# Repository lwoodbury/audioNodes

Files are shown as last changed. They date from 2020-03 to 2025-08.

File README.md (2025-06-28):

# audioNodes
Raspberry Pi based Smart Speaker Network designed to run Pure Data patches for sonic arts. 

- small and fairly powerful with good audio quality (I2S 3W amplifier)
- contains a Lipo battery and manages charging via USB micro
- has a smart power switch (safe shutdown and power off)
- everything shared here under Creative Commons Attribution-ShareAlike 4.0 International License, the Raspberry Pi image *, laser cut designs, code and circuit designs. The safe shutdown circuitry and code are inspired by the NeonHorizon/lipopi repo which is covered by a GPL 3.0 licence. Go forth and prosper...

<br />This work is licensed under a <a rel="license" href="http://creativecommons.org/licenses/by-sa/4.0/">Creative Commons Attribution-ShareAlike 4.0 International License</a>.

The idea is to run audio nodes that can communicate with each other using OSC in PD and eventually add sensors and microphone input (and possibly some extra output functionality). The hardware is a development from my digital 'birds' installation: https://www.dotlib.org/home#/forest-of-imagination-2018/

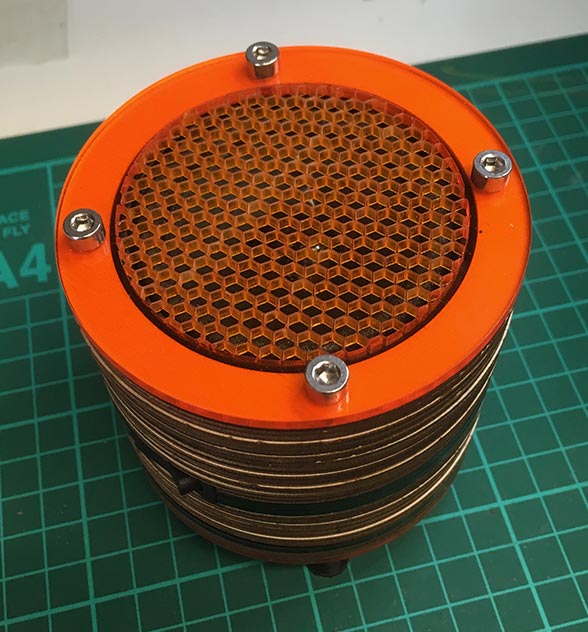
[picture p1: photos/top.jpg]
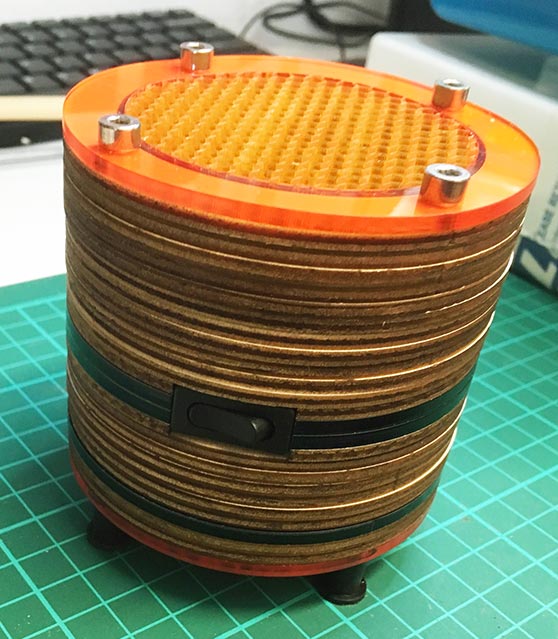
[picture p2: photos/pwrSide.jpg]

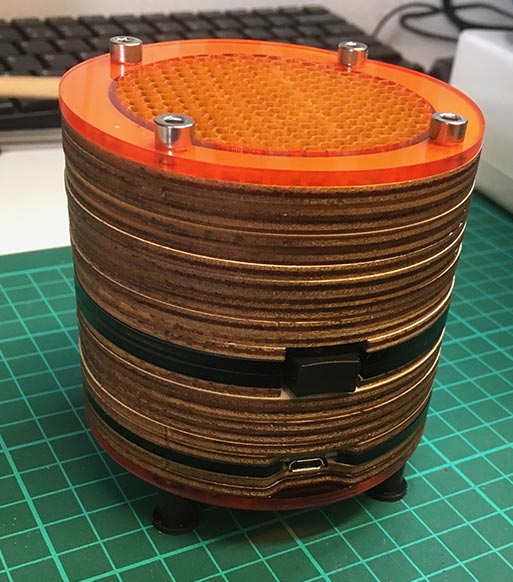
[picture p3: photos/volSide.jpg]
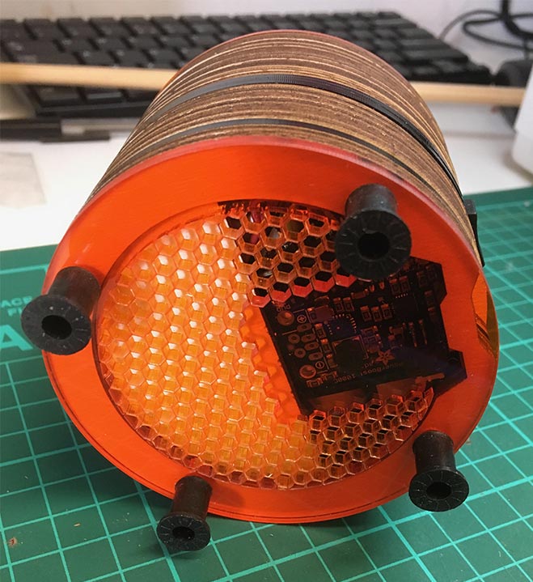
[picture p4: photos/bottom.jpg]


This project is at an early stage and the documentation is not yet as clear as it could be, I have just taken on a new full time job and am not sure when I can next update it or add details on the OSC communication part. Happpy to accept any help in this respect!

To build your own, check out the BOM (bill of materials) spreadsheet for required components and follow the 'Building an Audio Node' document with reference to the 'build stage photos' and notes. The lasercut designs make use of a deep engrave to go around some of the components, you will have to work this out based on your material and laser cutter model.

* Raspberry Pi image can be download from here: https://www.dropbox.com/s/5uapjz6rh7yxo8m/raspbianImage.img.zip?dl=1

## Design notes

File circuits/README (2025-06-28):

The power management circuit and code was inspired by NeonHorizon's 'lipopi' repo:
https://github.com/NeonHorizon/lipopi

Included here is a stripboard version and a PCB version, currently the case designs are based on the stripboard version. 

Use the file here to make new PCBs; unfortunately the original version of the KiCad project was lost but you can make new gerbers from this one:
..\circuits\powerManager\PCB files\Recovered_LiPoPiShutdown\LiPoPiShutdown.kicad_pcb

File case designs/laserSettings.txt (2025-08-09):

Trotec Speedy 360

Cut: P 100 V 1.5
Deep engrave 1mm: P 50 V 34

Lose 5mm from each side of strip on layer 11
Layer 23 engrave needs to be deeper 
Layer 24 can be lost?

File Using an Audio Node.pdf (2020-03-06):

## Using an Audio Node

## Turning it off and on

The frosted/clear section allows you to see the Raspberry Pi’s green light, when it is flashing it means disk activity. On the base you can also see the Power Boost board lights.

The power button must be held on for a short time for the power to stay up. Through the frosted section of the case you can see the Raspberry Pi’s green light flashing to indicate activity as it starts up. When the light is solid the Pi is ready, you should hear the speaker pop and then if you have set your PD patch to open on boot it should start a moment later.

To turn off you can do a short click of the button, the device should kill PD, start a safe shutdown and then once that is complete cut the power on the Power Boost board at which time the blue light will go off. This takes a little time, a minute or two.

## Controlling the device via a terminal with SSH

Make sure your computer/device is on the same network as the pi and open a terminal. SSH into the pi with: ssh pi@raspberrypi.local password: raspberry , or whatever hostname and password you have set up already
(kudos to ‘Termius’ which enables you to store snippets of terminal commands and communicate with the device from your phone easily)

Some useful SSH commands:
Software Mixer – alsamixer
Speaker test (noise) - speaker-test -c2

Speaker test (WAV) - speaker-test -c2 --test=wav -w /usr/share/sounds/alsa/Front_Center.wav

Install MP3 stream player - sudo apt-get install -y mpg123

Play Radio 6 stream - mpg123 http://bbcmedia.ic.llnwd.net/stream/bbcmedia_6music_mf_p

Edit boot config file - sudo nano /boot/config.txt
Crontab edit - crontab -e
Configure Raspberry Pi - sudo raspi-config

Set time - sudo date -s "9/26/2018 9:35"

Shutdown - sudo shutdown -h now

Update - sudo apt-get update && sudo apt-get upgrade

Wifi scan - sudo iwlist wlan0 scan

## Accessing a Remote Desktop

I have left VNC enabled and am running in GUI mode (i.e. not headless) so you should be able to connect with a VNC client of which there are several free ones, I use ‘VNC Viewer’.

You need to put in your hostname and password details and again assure you are on the same network as the Pi. If you can not connect, then SSH in as above and:

1. Run configuration tool with: sudo raspi-config
2. Check that VNC is enabled (in ‘Interfacing Options’)
3. Check that boot options are not set to go into console, i.e. run headless

## Transferring Files

Transferring files can be done via FTP, again there are several free options, I use ‘Filezilla’. You need to put in your hostname and password details and assure you are on the same network as the Pi. You can then simply drag and drop files from your system to the device.

## Working with PD

I have not had much success trying to get anything other than PD vanilla running on the Pi Zero, but in fairness I have not tried for a while and it could be possible to run one of the more feature rich forks such as Purr Data or perhaps the L2Ork distribution.

## Getting your PD patch to run on startup

Refer to the ‘Building and Audio Node’ document, specifically the section titled ‘To create your own image’, steps 17 & 18 (or you could just rename your patch and move it to the same place as the original one)

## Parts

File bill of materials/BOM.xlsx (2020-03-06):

Item | Cost | Dimensions (mm) | Link
Speaker (66mm) | £5.50 | 66x66x29 | https://shop.pimoroni.com/products/5w-4-ohm-65mm-full-range-speaker
DAC & amplifier: Adafruit Speaker Bonnet | £12.00 | 65x30x7.2 | https://shop.pimoroni.com/products/adafruit-i2s-3w-stereo-speaker-bonnet-for-raspberry-pi-mini-kit
Lipo battery (2000mAh) | £13.50 | 64x35.5x5.3 | https://shop.pimoroni.com/products/lipo-battery-pack?variant=20429082247
Lipo boost/charger: Adafruit PowerBoost 1000c | £18.30 | 10 | https://shop.pimoroni.com/products/powerboost-1000-charger-rechargeable-5v-lipo-usb-boost-1a-1000c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
Raspberry Pi Zero WH | £13.02 | 65x30x5 | https://shop.pimoroni.com/products/raspberry-pi-zero-wh-with-pre-soldered-header
Micro SD Card | £6.65 |  | https://www.mymemory.co.uk/samsung-32gb-evo-micro-sd-card-sdhc-uhs-i-u1-adapter-95mb-s.html
Acrylic sheet (3x400x600mm) [main body] | £7.50 |  | https://www.kitronik.co.uk/4365-black-opaque-perspex-sheet-3mm-x-600mm-x-400mm.html
Acrylic sheet (3x200x100mm) [base & top] | £0.80 |  | https://www.kitronik.co.uk/43115-grey-perspex-sheet-frosted-3mm-x-600mm-x-400mm.html
Acrylic sheet (3x100x100mm) [illuminating section] | £0.40 |  | https://www.kitronik.co.uk/4391-white-frosted-perspex-sheet-3mm-x-600mm-x-400mm.html
On/Off button (momentary rocker) | £2.45 |  | https://sinolec.co.uk/en/miniature-rocker-switches/1211391-slim-rocker-switch-momentary-on.html
Volume rocker button: RS stock 734-6883 | £1.77 |  | https://uk.rs-online.com/web/p/rocker-switches/7346883/?searchHistory=%7B%22enabled%22%3Atrue%7D
4x M4 80mm screws | £1.25 |  | https://www.kayfast.co.uk/view-product/SOCKET-CAP-SCREWS-DIN-912-A2-ST-ST
4x M4x11mm rubber nuts | £1.50 |  | https://www.kayfast.co.uk/view-product/RUBBER-WELL-NUTS
Sundries:
Stripboard (10x10 holes) | £0.35
Resistors (2x 100K, 1x 10K, 1x 33K) | £0.08
Diode (1x 1N4001) | £0.05
Capacitor (1x 100uF) | £0.26
Right angle header pins (9x) | £0.80
Header sockets (1x 5, 2x 2) | £0.80
Wires, solder etc
Postage and sundries | £6.00
TOTAL | £92.98
Laser Cutting time:
Main sides | 35 mins
2x ends | 12 mins
1x frosted section | 3 mins
Cleaning up of parts | 10 mins
Micro SD preparation and software config time | 15 mins
Soldering power board and parts prep time | 30 mins
Assembly time + connecting wires soldering | 30 mins
Ordering time | 30 mins

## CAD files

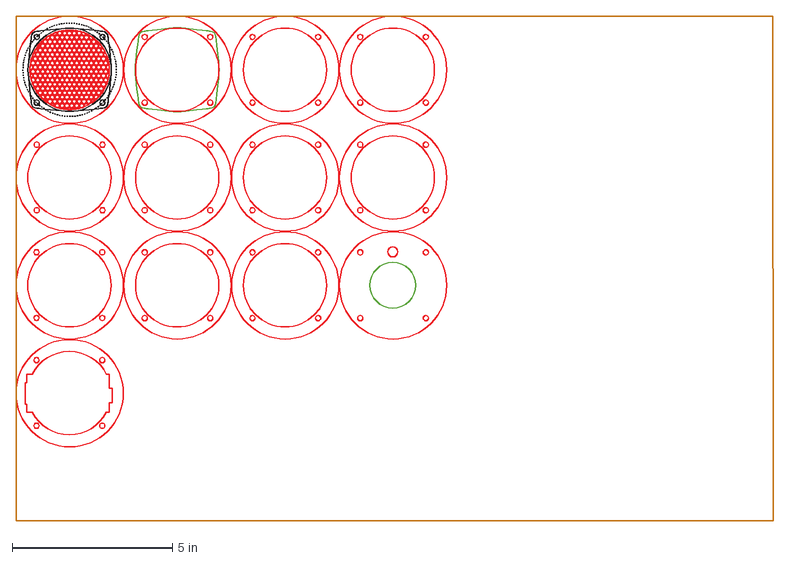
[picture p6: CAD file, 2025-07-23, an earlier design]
case designs/archive/case.dxf
23.6 x 15.8 in

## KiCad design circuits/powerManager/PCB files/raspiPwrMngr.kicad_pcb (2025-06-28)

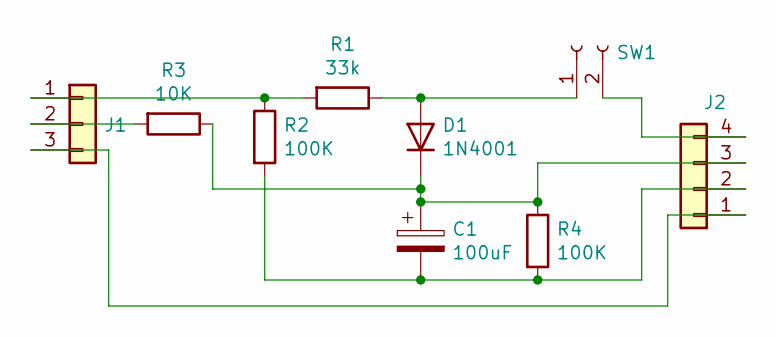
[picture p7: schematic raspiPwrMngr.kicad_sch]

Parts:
C1: 100uF; CP_Radial_D8.0mm_P5.00mm
D1: 1N4001; D_DO-41_SOD81_P10.16mm_Horizontal
J1: Conn_01x03; JST_PH_S3B-PH-K_1x03_P2.00mm_Horizontal
J2: Conn_01x04; JST_PH_S4B-PH-K_1x04_P2.00mm_Horizontal
R1: 33k; R_Axial_DIN0207_L6.3mm_D2.5mm_P10.16mm_Horizontal
R2, R4: 100K; R_Axial_DIN0207_L6.3mm_D2.5mm_P10.16mm_Horizontal
R3: 10K; R_Axial_DIN0207_L6.3mm_D2.5mm_P10.16mm_Horizontal
SW1: Conn_01x02_Socket; JST_PH_S2B-PH-K_1x02_P2.00mm_Horizontal

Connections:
unnamed: D1.2 (A), R1.1, SW1.1
unnamed: C1.1, D1.1 (K), J2.3, R3.1, R4.1
unnamed: J1.1, R1.2, R2.1
unnamed: J1.2, R3.2
unnamed: J1.3, J2.1
unnamed: C1.2, J2.2, R2.2, R4.2
unnamed: J2.4, SW1.2

Board: 2 copper layers, 9 parts (0 on the bottom side), 7 nets, no tracks yet.

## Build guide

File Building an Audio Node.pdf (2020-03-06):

## Building an Audio Node

## Part 1 – Getting the SD card image sorted

You can either download the pre-built image or build the image yourself, if using the prebuilt you will still need to set up your Wifi networks as shown below.

Using the prebuilt image
Download the pre-built image from here, this includes Raspbian, PD, volume control button service, shutdown service that works together with the external circuit and Power Boost board. You will need to set up the wifi credentials to connect to the device:
1. Use ‘Pi Filler’ app or similar to load the image onto the SD card
2. Mount the SD card from a computer
3. Create a text file in the root folder and rename it: wpa_supplicant.conf
4. Use a text editor to edit the wifi settings file you have just created with the entry below, you can add several networks. For example you can set up your home, work, a little portable router and an access point on your phone to cover all bases. You can also add a connection priority (e.g. ‘priority=1’) to each entry:

ctrl_interface=DIR=/var/run/wpa_supplicant GROUP=netdev update_config=1
country=UK

network={
ssid="YOURSSID"
psk="YOURPASSWORD"
scan_ssid=1
}
5. Eject the SD card and run through steps 6 – 11 in the section below

## To create your own image:

1. Download Raspbian image and unzip: https://www.raspberrypi.org/downloads/raspbian/
a. [You will need the desktop version if you plan to VNC across to remote control the desktop using the GUI. This can be useful to set up PD and then you can disable the GUI, i.e run ‘headless’, later]
2. Use PiFiller or similar to load up SD card with the image
3. Add a text file for wifi settings to root folder called: wpa_supplicant.conf

4. Edit the wifi settings file with following, you can add several networks. For example you can set up your home, work, a little portable router and an access point on your phone to cover all bases. You can also add a connection priority (e.g. ‘priority=1’) to each entry:
a. ctrl_interface=DIR=/var/run/wpa_supplicant GROUP=netdev
b. update_config=1
c. country=UK
d. network={
e. ssid="YOURSSID"
f. psk="YOURPASSWORD"
g. scan_ssid=1
h. }
5. Add a blank text file to root folder simply called ‘ssh’ with no file type
6. Insert SD card and boot up Pi
7. Make sure your computer/device is on the same network as the pi and open a terminal. SSH into the pi with: ssh pi@raspberrypi.local password: raspberry , or whatever hostname and password you have set up already
(kudos to ‘Termius’ which enables you to store snippets of terminal commands and communicate with the device from your phone easily)
8. Run configuration tool with: sudo raspi-config
9. Change hostname (in ‘Network Options’), change password, enable VNC (in ‘Interfacing Options’), you may also want to set the locale and time zone while you are here
10. If you are going to want to schedule things you will need to set the time which you can do manually (sudo date -s "2/26/2020 9:35"), but it will be forgotten when the battery is disconnected. Alternatively you could try installing NTP so it updates automatically when you have a network connection: sudo apt-get install ntp
11. Reboot Pi
12. Do the updates (it may take a while). Run:

sudo apt-get update && sudo apt-get upgrade

13. Install PD: sudo apt-get install puredata
14. Set up Adafruit Speaker Bonnet: https://learn.adafruit.com/adafruit-speakerbonnet-for-raspberry-pi/raspberry-pi-usage
15. Open PD, setup audio and SAVE audio settings! I needed to use portaudio driver to make it work, also need to set the output device to ‘softvol’ to be able to control the volume from the alsamixer and via the button code.
16. Copy main PD patch across – Use an FTP client

17. Set up a script to open PD patch and run without the GUI if desired:
a. Create the script: sudo nano /home/pi/pdstart
b. Add following lines (watch filepath and case!!) :

sleep 5
pd -nogui -nomidi -verbose -stderr /home/pi/Documents/Pd/PDSamplePlay/playSample.pd sleep 5
c. Set privileges on script with:

sudo chmod 755 /home/pi/pdstart

d. Start script with : /home/pi/pdstart
(Can kill PD with: sudo killall pd )
18. You can add script to startup and schedule with crontab if desired: https://www.raspberrypi.org/documentation/linux/usage/cron.md
**NB- using cron reboot function may mean the script starts before home drive is mounted or audio is enabled etc, the lazy can simply add an arbitrary delay to the script and hope it sorts it, or systemd could be used to do it properly and start it later in boot process details for using systemd here: https://www.dexterindustries.com/howto/run-a-program-on-your-raspberry-pi-atstartup/
19. If you wish to cut the GUI side of the Pi and save system resources then go into raspi-config and select boot options to go into console, i.e. run headless
20. Disable Bluetooth if desired to save battery:
21. Edit boot config file: sudo nano /boot/config.txt
… and add these lines to bottom:

# Disable Bluetooth

dtoverlay=pi3-disable-bt

## Part 2 – Getting the Volume and Power Button sorted

## Volume control – connected buttons to GPIO pins 4 and 17

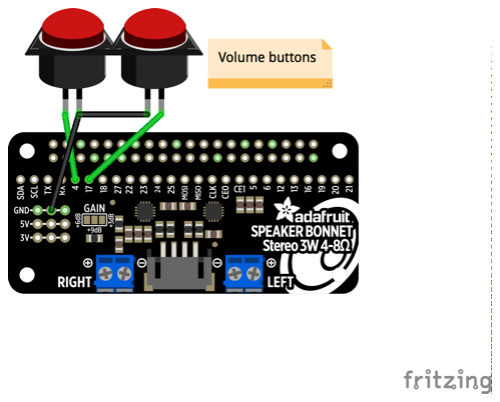
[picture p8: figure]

NB - The below works for system sound control via alsamixer, this means you may need to set the output device in PD to ‘softvol’ to get it to work

1. To create python script - sudo nano volButton.py
2. Insert the Python script code below:

import RPi.GPIO as GPIO
import time

GPIO.setmode(GPIO.BCM)

GPIO.setup(4, GPIO.IN, pull_up_down=GPIO.PUD_UP) GPIO.setup(17, GPIO.IN, pull_up_down=GPIO.PUD_UP)

while True:
volUp = GPIO.input(4)
if volUp == False:
print('UP Button Pressed')
#amixer set PCM 3%+

from subprocess import call call(["amixer", "set", "PCM", "3%+"]) #amixer set Speaker 5%+
time.sleep(0.2)

volDwn = GPIO.input(17)
if volDwn == False:
print('DOWN Button Pressed')
#amixer set PCM 3%-

from subprocess import call call(["amixer", "set", "PCM", "3%-"]) #amixer set Speaker 5%-
time.sleep(0.2)
3. Set the script up to run as a service, follow ‘Method 4: SYSTEMD’ at this link or the one below with the service code below.
- https://www.dexterindustries.com/howto/run-a-program-on-your-raspberry-pi-atstartup/#local
- https://github.com/bruceiow/rPiVolumeControl/blob/master/setup.md

[Unit]
Description=Volume Controller
After=multi-user.target

[Service]
Type=idle
ExecStart=/usr/bin/python /home/pi/volButton.py > /home/pi/volButton.log 2>&1

[Install]
WantedBy=multi-user.target

## On/off button – using ‘lipopi’ resource

NB – Note use of pin 27 instead of pin 18 as used in the ‘lipopi’ resource. This is because the speaker bonnet makes use of pin 18

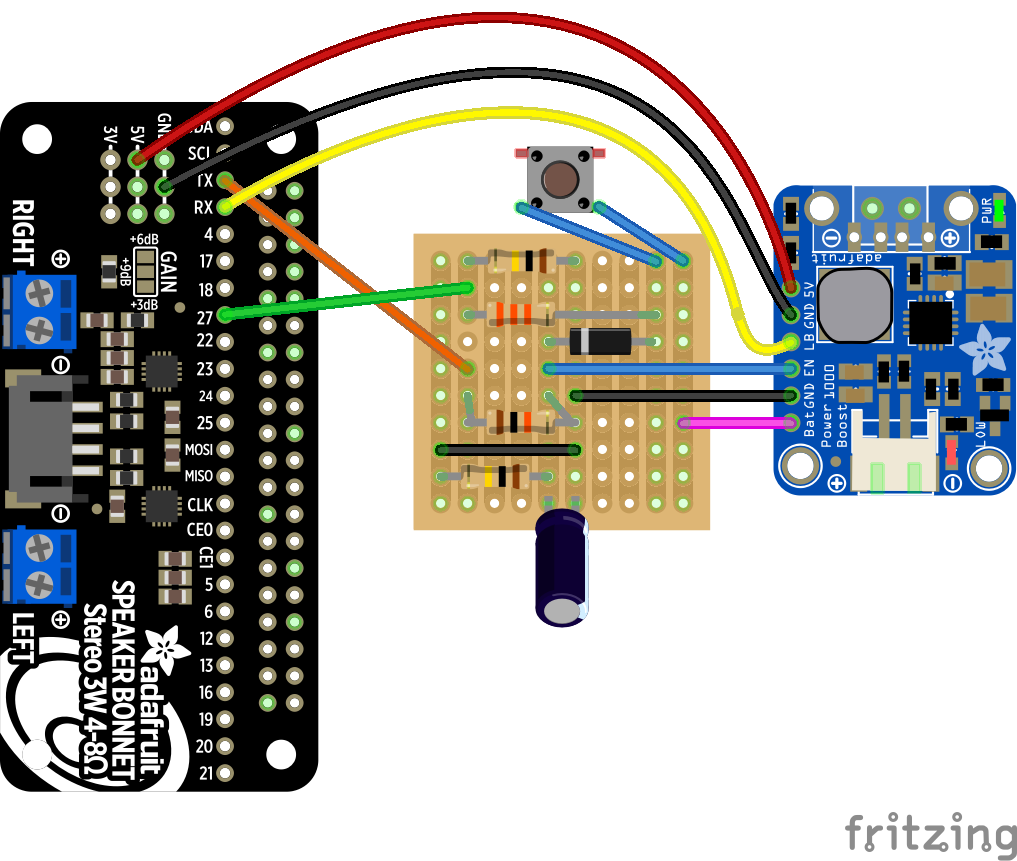
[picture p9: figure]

LiPoPi
https://github.com/NeonHorizon/lipopi/blob/master/README.power_up_power_down.md

[NB I found that the service was failing when I tried to run it and had to chmod on the original script to make it executable (probably because I added the script myself instead of copying the repository one over): sudo chmod +x lipopi.py]

I wanted the shutdown button press to also kill PD so I added to the lipopi.py script where shutdown or low battery is triggered: os.system("sudo killall pd")
e.g:

# Detect when the switch is pressed - wait shutdown_wait seconds - then shutdown

def lipopi_user_shutdown(channel):
global lipopi

cmd = "sudo wall 'System shutting down in %d seconds'" % lipopi['shutdown_wait'] os.system(cmd)
os.system("sudo killall pd")
time.sleep(lipopi['shutdown_wait'])

msg = time.strftime("User Request - Shutting down at %a, %d %b %Y %H:%M:%S +0000\n", time.gmtime())
lipopi['logfile_pointer'].write(msg)
lipopi['logfile_pointer'].close()
GPIO.cleanup()
os.system("sudo shutdown now")

# Respond to a low battery signal from the PowerBoost and shutdown # Pin goes low on low battery

def lipopi_low_battery_shutdown(channel):
global lipopi cmd = "sudo wall 'System shutting down in %d seconds'" % lipopi['shutdown_wait'] os.system(cmd)
os.system("sudo killall pd")
time.sleep(lipopi['shutdown_wait'])

msg = time.strftime("Low Battery - Shutting down at %a, %d %b %Y %H:%M:%S +0000\n", time.gmtime())
lipopi['logfile_pointer'].write(msg)
lipopi['logfile_pointer'].close()
GPIO.cleanup()
os.system("sudo shutdown now")

## Part 3 – The Hardware

Download the laser cutter files from the repository.

These designs are based on 3mm stock, though remember that acrylic sheet is not always uniform so it is possible you may end up adapting the design. You can use wood stock, but the sections that hold components have some delicate thin structures that require some strength and are best suited to acrylic.

Note the use of deep engraves to allow components to be held snugly in the case and allow for a smaller overall size. On my laser cutter I use full power and a speed of 150 to go a good halfway into the 3mm stock, this leaves a lot of dust residue so go over the engraved sections with a flat head screwdriver of a small file to clear it out.

The bill-of-materials (BOM) can also be found in the repository, this lists all the components needed, costs and potential suppliers.

The design file lays out the parts in assembled order so it can be used as a blueprint, the volume button and power button need to be connected as shown above with the wires threaded through the case to the required location. I find it best to cut them a little long and then trim them to size on assembly. I find it useful to use header pins and sockets when assembling the circuits as everything for ease of assembly/disassembly/troubleshooting, but you can solder wires directly. NB – you can use thin or ribbon wire for most connections, but use some decent wires for the 5V and GND connections.

Assembly photos can also be found in the repository along with circuit design files.

## Charging the battery

The PowerBoost

To do:
Startup sound, shutdown sound, button sound
Startup sound - https://raspberrypi.stackexchange.com/questions/3632/running-headlesshow-do-i-create-a-boot-sound

N.B:

If you get SSH error connecting :
May need to delete hostname/IP from known hosts file if you get ssh refusal due to suspected spoofing: /Users/yourUserName/.ssh/known_hosts

Change volume once in headless mode:
Type: alsamixer to enter command line mixer, use F6 to swap between sound cards. If you already have an ssh window open and PD is taking over, you can open another ssh window to edit the volume at the same time.

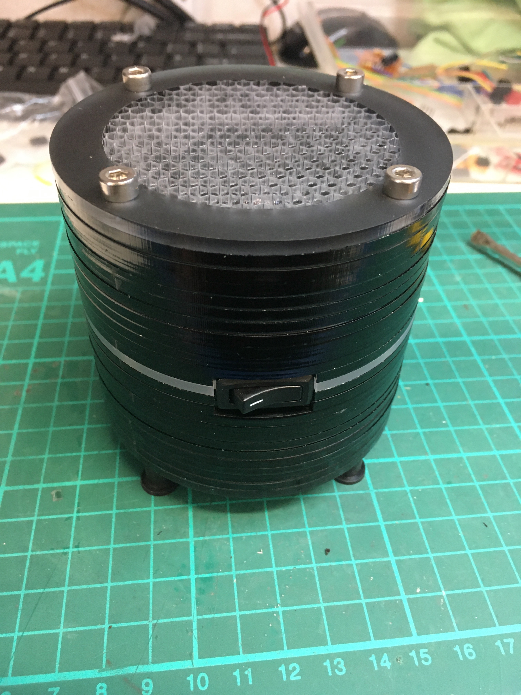
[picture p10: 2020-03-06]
build stage photos/IMG_1568.jpg

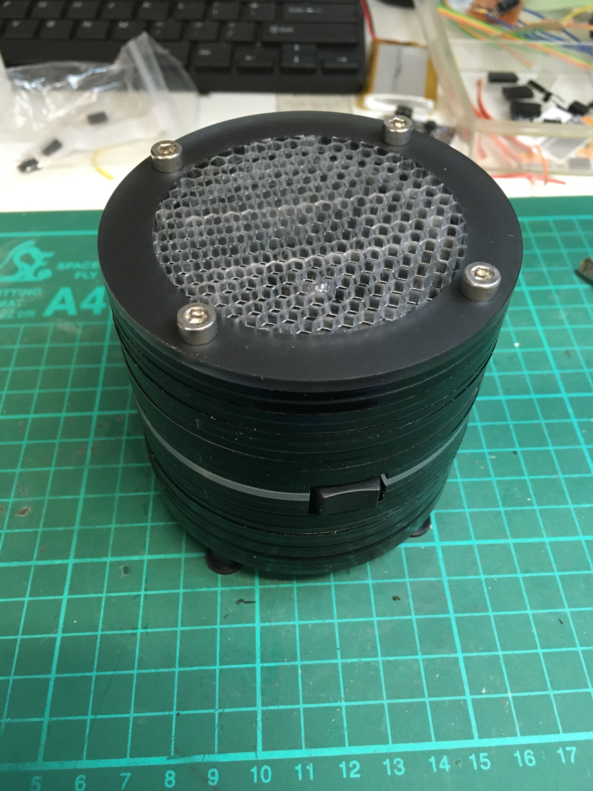
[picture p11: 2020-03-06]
build stage photos/IMG_1566.jpg

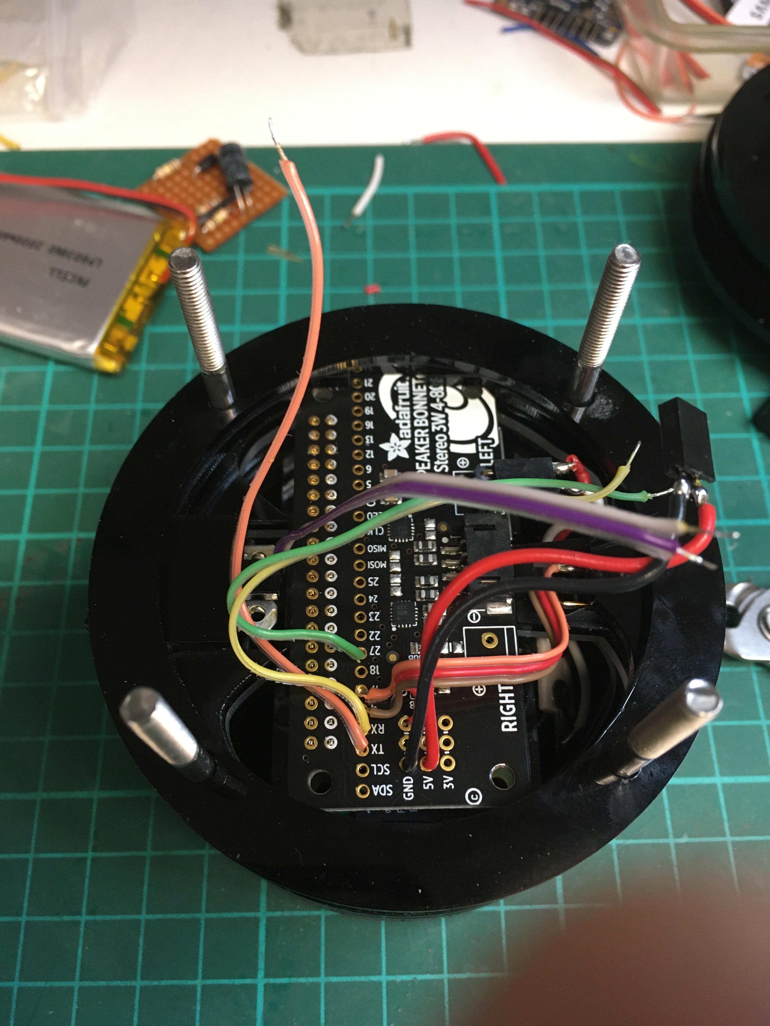
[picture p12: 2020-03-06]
build stage photos/IMG_1557.jpg

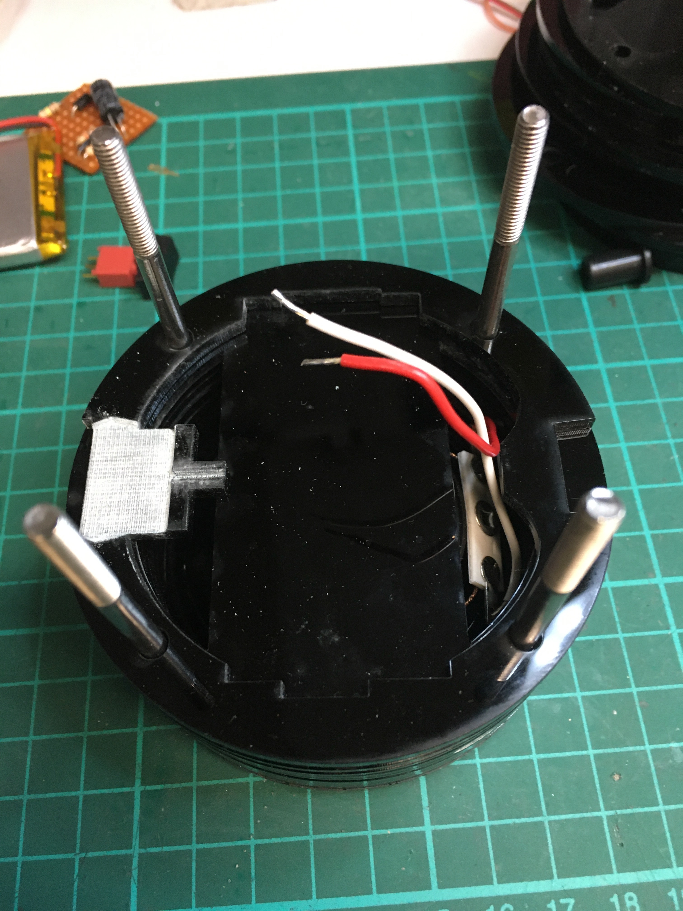
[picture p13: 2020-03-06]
build stage photos/IMG_1547.jpg

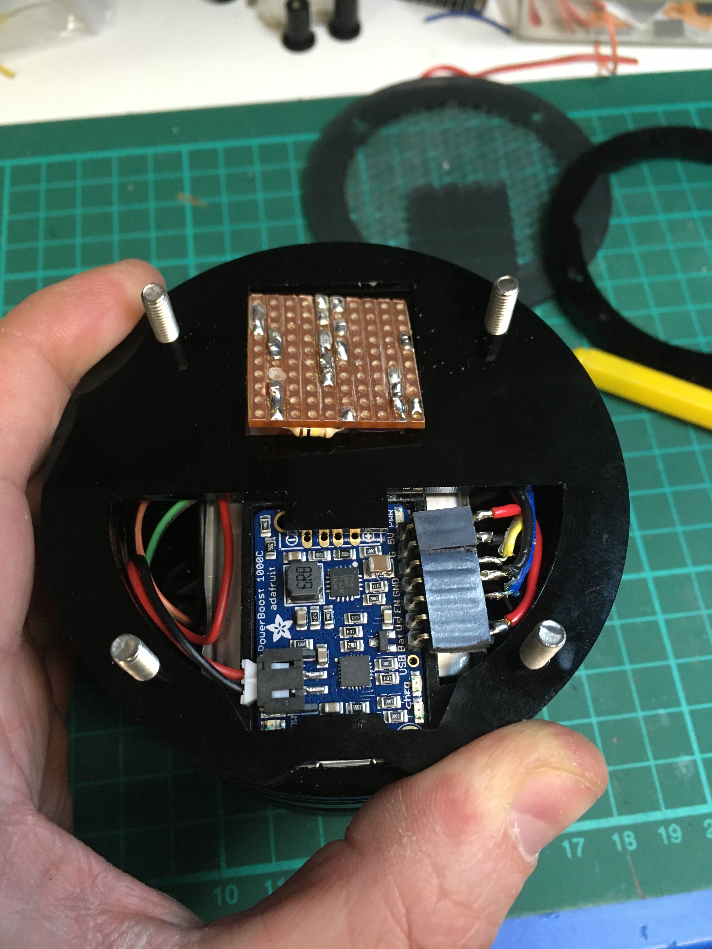
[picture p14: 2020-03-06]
build stage photos/IMG_1564.jpg

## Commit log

2020-03-06 First commit
    Need to add support for lfs so can include raspbian image, or just host somewhere
    [BOM.xlsx, case.dxf]
2025-06-28 Update circuits with PCB version
    Use the file here to make new PCBs, unfortunately the original version of the KiCad project was lost but you can make new gerbers from this one:
    ..\circuits\powerManager\PCB files\Recovered_LiPoPiShutdown\LiPoPiShutdown.kicad_pcb
    [LiPoPiShutdown.kicad_pcb, PowerboostOnOffStrip.fzz, raspiPwrMngr.kicad_pcb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]
2025-07-23 Updated case designs
    Tidied up and archived old files
    Created new svg and cdr files in preparation for power manager pcb
    [case.dxf]
2025-07-23 Update caseUpdated.svg
    Fixed layer order, in prep for power manage pcb
2025-07-24 Rescaled case design
    Seems there was a slight issue with scaling, have rescaled case outer diameter to 85mm
2025-07-27 Created PCB case design
2025-08-09 PCB case reordered, pre shrink
